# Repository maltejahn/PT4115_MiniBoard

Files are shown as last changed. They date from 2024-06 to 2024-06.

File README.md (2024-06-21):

Aim:
- small board with a PT4115 LED constant current source -> up to 1.2 A
- dimmable with a 5V PWM signal (PWM frequency up to 50 kHz acc. to datasheet)
- single sided so it can be mounted to a heat sink (using 2 M4 Bolts)
- connected using pin header (0.1") of soldered directly
- shouldnt smoke immediately

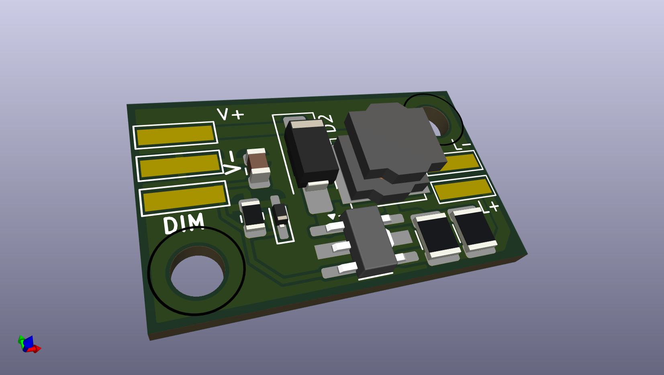
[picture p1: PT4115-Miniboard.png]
What a great PCB ;-)


ToDo:
- some measurements...

Tasks:
- finalize schematic  - done
- finalize pcb - done
- Gerbers, order pcb - tbd
- BOM, assemble instructions - tbd
- assemble - tbd
- test - tbd
- report - tbd

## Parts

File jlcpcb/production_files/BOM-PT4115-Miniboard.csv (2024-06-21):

Comment | Designator | Footprint | LCSC
TestPoint | J5 | Solder_Pad_5x1.3mm
PT4115 | U1 | SOT-89-5_Handsoldering
TestPoint | J6 | Solder_Pad_5x1.3mm
TestPoint | J4 | Solder_Pad_5x1.3mm
MountingHole | H2 | MountingHole_3.2mm_M3_ISO14580
0R2 | R2 | R_1210_3225Metric
TestPoint | J2 | Solder_Pad_5x1.3mm
SRN6045TA-470M | L1 | L_Bourns_SRN6045TA
BZX384-B5V1,115 | D1 | D_SC-80_HandSoldering
0R2 | R1 | R_1210_3225Metric
MountingHole | H3 | MountingHole_4.3mm_M4
TestPoint | J3 | Solder_Pad_5x1.3mm
SS14-LTP | D2 | D_SMA_Handsoldering
nc | C1 | C_0805_2012Metric
MountingHole | H1 | MountingHole_3.2mm_M3_ISO14580
10k | R3 | R_0805_2012Metric

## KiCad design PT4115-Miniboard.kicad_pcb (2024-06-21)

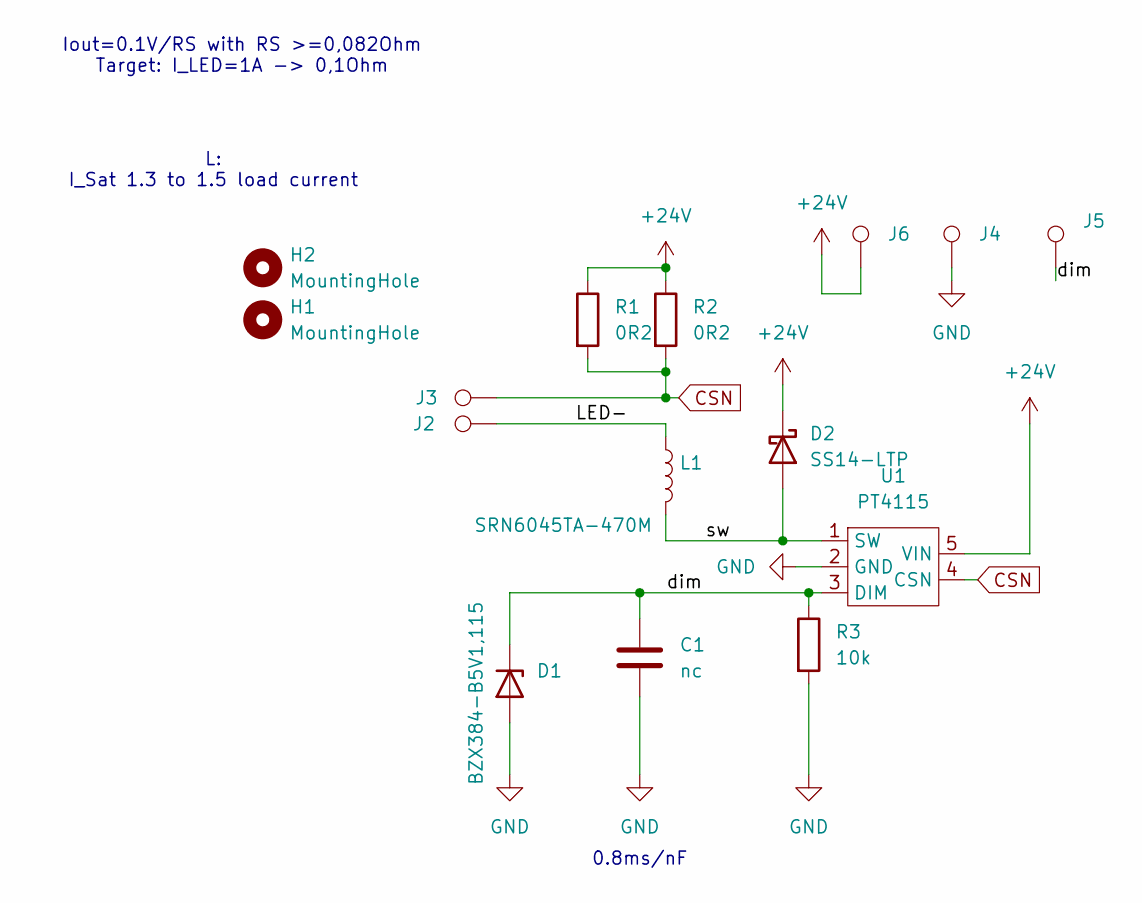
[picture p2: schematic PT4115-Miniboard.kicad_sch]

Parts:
C1: nc; C_0805_2012Metric
D1: BZX384-B5V1,115; D_SC-80_HandSoldering; Mouser 771-BZX384-B5V1-T/R
D2: SS14-LTP; D_SMA_Handsoldering; Mouser 833-SS14-LTP
H1, H2: MountingHole; MountingHole_3.2mm_M3_ISO14580
J2, J3, J4, J5, J6: TestPoint; Solder_Pad_5x1.3mm
L1: SRN6045TA-470M; L_Bourns_SRN6045TA; Mouser SRN6045TA-470M
R1, R2: 0R2; R_1210_3225Metric; Mouser RCWE1210R200FKEA
R3: 10k; R_0805_2012Metric; Mouser RC0805FR-0710KL
U1: PT4115; SOT-89-5_Handsoldering

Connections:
+24V: D2.1 (K), J6.1, R1.1, R2.1, U1.5 (VIN)
/LED-: J2.1, L1.1
/dim: C1.1, D1.1 (K), J5.1, R3.1, U1.3 (DIM)
/sw: D2.2 (A), L1.2, U1.1 (SW)
CSN: J3.1, R1.2, R2.2, U1.4 (CSN)
GND: C1.2, D1.2 (A), J4.1, R3.2, U1.2 (GND)

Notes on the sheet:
Iout=0.1V/RS with RS >=0,082Ohm Target: I_LED=1A -> 0,1Ohm
L: I_Sat 1.3 to 1.5 load current
0.8ms/nF

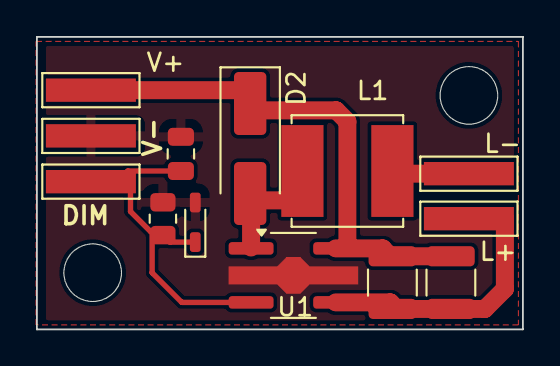
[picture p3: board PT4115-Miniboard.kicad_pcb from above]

Board: 2 copper layers, 27.0 x 16.2 mm, 15 parts (0 on the bottom side), 6 nets.
